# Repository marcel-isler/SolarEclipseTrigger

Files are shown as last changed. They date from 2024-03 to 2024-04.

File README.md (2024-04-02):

Application that remote controls a Nikon D850 during a Solar Eclipse.  The software features the ability to configure different phases in relation to C1 - C4 that can take different sets of photos, including in-camera brackets.  It uses a CH340 USB Relay as a remote shutter trigger.  Instructions on how to create the shutter trigger are in the attached document.

Pre-Requisite:
Install the latest USB Relay Driver:
https://github.com/marcel-isler/SolarEclipseTrigger/blob/main/USB%20Relay/Driver/CH341SER%20v3.8.zip
Install the latest C++ Redistributable:
https://learn.microsoft.com/en-us/cpp/windows/latest-supported-vc-redist?view=msvc-170

Get the executable from the Release Link:
https://github.com/marcel-isler/SolarEclipseTrigger/releases/tag/v0.9.4

These are the steps I'm taking during a run:
1. Format the memory cards in the Camera
2. Set the Camera to LiveView and move the zoom rectangle near the center (the Nikon SDK doesn't have a method to change the location of that rectangle)
3. Clear out the directory where the computer will write the images
4. Connect Camera and USB Relay to Computer (I'm using a USB Hub on the tracker that is connected to the Computer of USB 3.2)
5. Connect the USB Relay to the Remote Shutter Cable on the D850
6. Power on the Camera, verify that you can see the camera from the Computer's File Explorer
7. Start SolarEclipseTimer application
8. Click on the 'Event Info' tab and make sure your event times are correct for your location.  Use a phone app like Solar Eclipse Timer to find the correct contact times for your exact location.  If you had to make any changes, close SolarEclipseTrigger and go back to Point 7.
9. Click on the 'Full Log', then 'Session', then 'Full Log' and 'Session' tab once more (there is a bug with the logging showing up I still have to figure out)
10. Click on 'Set Camera Date Time' in the upper left corner of the application
11. Click on 'Set Focus' tab
12. Click 'Start Focus Procedure' and frame the sun and set the focus.
13. Click 'End Focus Procedure'
14. If this is the REAL run, that's all that should be necessary and the application will countdown to the different phases.
15. If you're running a simulation, uncheck the 'Use System Time' in the Session tab
16. Enter the date and time you want to simulate and press Start.  To do a full run, start 2 minutes before your C1 time, if you just want to test totality, start 2 minutes before C2.

Make sure you run at LEAST one full run with all the equipment setup exactly how you will do it to make sure batteries hold up, timings are ok etc.  Preferably do a full run with the event date in Event Info changed to the current date and the use the actual even times as if it was April 8th.

Camera Settings:
- Camera set to not review photos after they are taken
- Set Live View Photography to CL1
- Just use the XQD / CFExpress card and set the second card to overflow.  Writing to both cards makes the camera slower and can cause issues with the timing of the sequence.
- Disable WiFi and Bluetooth
- Set Camera to Airplane Mode
- Set Camera to Auto Focus and Lens to A/M (needed for software controlled focus drive to work)
- Set Camera to use Back Button Focusing (don't want to trigger autofocus when we take an exposure)

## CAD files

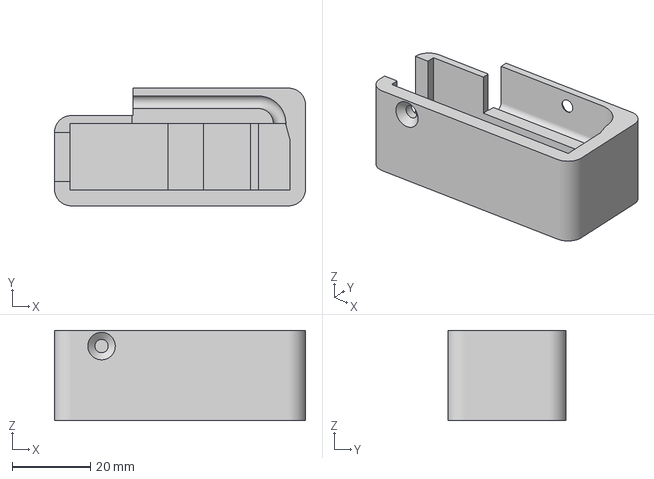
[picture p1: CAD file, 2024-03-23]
USB Relay/Case 3D model/USB Relay Remote Shutter Case Bottom v5.3mf
64.0 x 30.0 x 23.0 mm

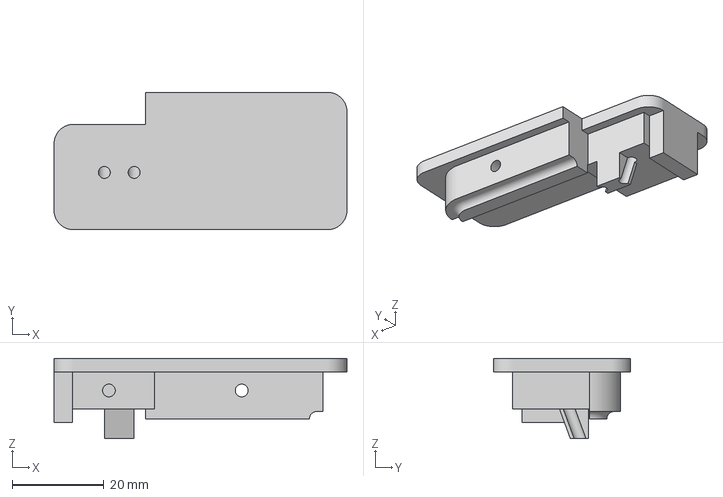
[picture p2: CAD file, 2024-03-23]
USB Relay/Case 3D model/USB Relay Remote Shutter Case Top v5.3mf
64.0 x 30.0 x 17.5 mm

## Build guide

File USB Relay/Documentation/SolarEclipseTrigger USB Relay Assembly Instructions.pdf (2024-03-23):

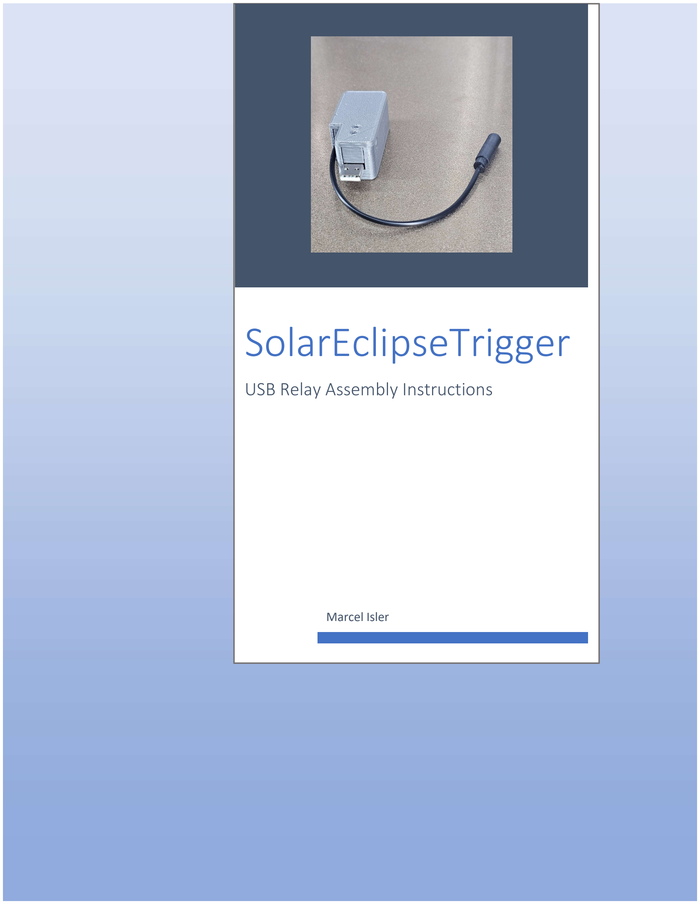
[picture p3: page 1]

# SolarEclipseTrigger

## USB Relay Assembly Instructions

Marcel Isler

## Contents

## 1. Required Materials

- 1 x CH340 USB Relay
- 1 x 2.5mm Female Jack to Bare Wire Open End
- 1 x 2.5mm-N1 10-PIN Remote Control Shutter Release Cable Cord for Nikon D850
- Either: 2 x Small Cable Ties or 1 x 3D printed case

## 2. Amazon Links

This is a list of links to get the materials. There are many vendors that carry those exact same parts, these are just examples. Also, I am not affiliated with any of the vendors below and don’t get any money from possible purchases.

### CH340 USB Relay:

https://www.amazon.com/Taidda-Durable-Lightweight-Intelligent-Control/dp/B07WFVN1FK

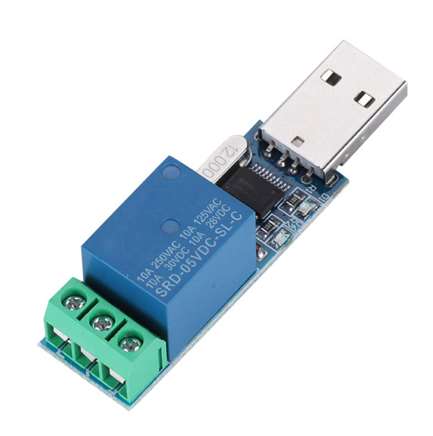
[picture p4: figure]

### 2.5mm Female Jack to Bare Wire Open End:

https://www.amazon.com/dp/B07ZT7JDNP

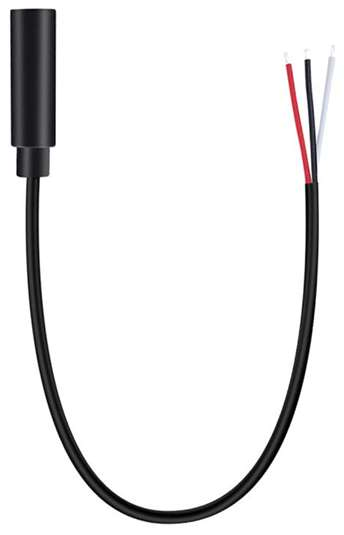
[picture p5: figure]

### 2.5mm-N1 10-PIN Remote Control Shutter Release Cable Cord for Nikon D850

https://www.amazon.com/Foto-Tech-2-5mm-N1-Shutter-Connecting/dp/B017MMBK6G

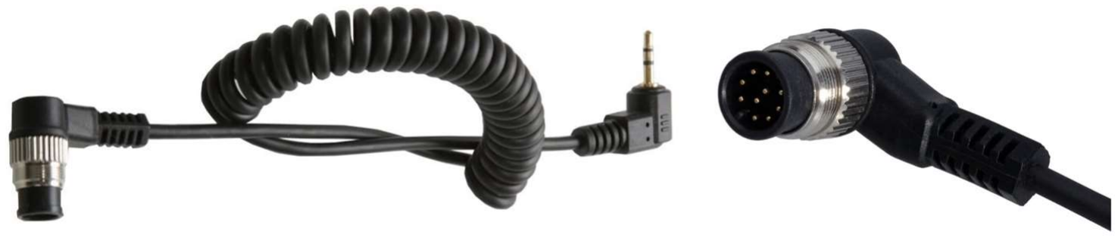
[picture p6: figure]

As an alternative, you can also get a remote shutter control with detachable cable as long as it has a 2.5mm jack plug. That way, should the relay fail for what ever reason, you still have a manual backup to triggering the camera without having to touch it. The more backup solutions we have, the more likely we are to succeed.
https://www.amazon.com/gp/product/B0BFWWC2Y3

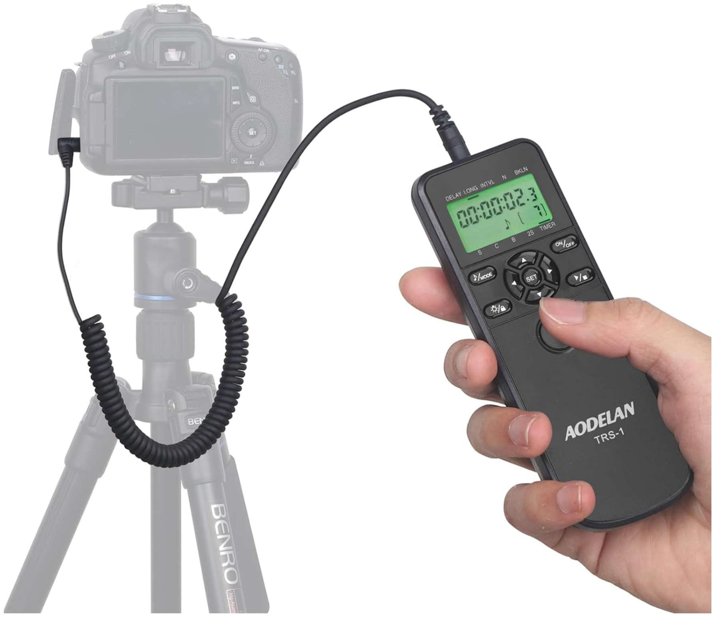
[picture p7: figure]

## 3. Wiring

Wiring up the USB Relay is simple. Strip a bit of insulation from the three wires of the 2.5mm jack cable, twist the red and white wire together, twist the copper end of the black wire by itself. Fold the two copper ends each in half to give it a bit more material inside the connector. Insert the black wire into the center of the Relay connector and the red and white wire pair into the left connector (as seen in the picture below).

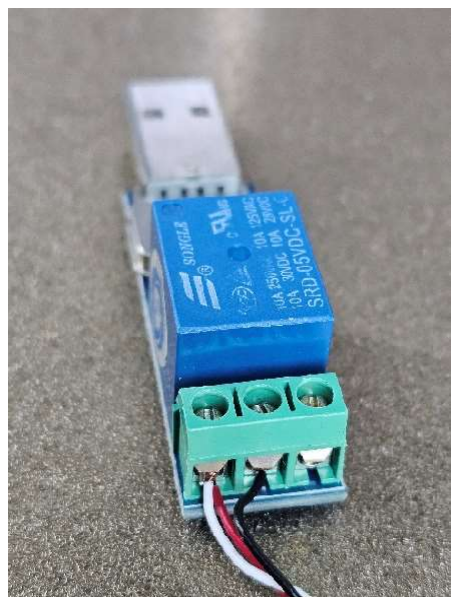
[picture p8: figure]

## 4. Assembly without the 3D case

If you don’t have access to a 3D printer, you can just use two small cable ties to keep the jack cable in place as seen below.

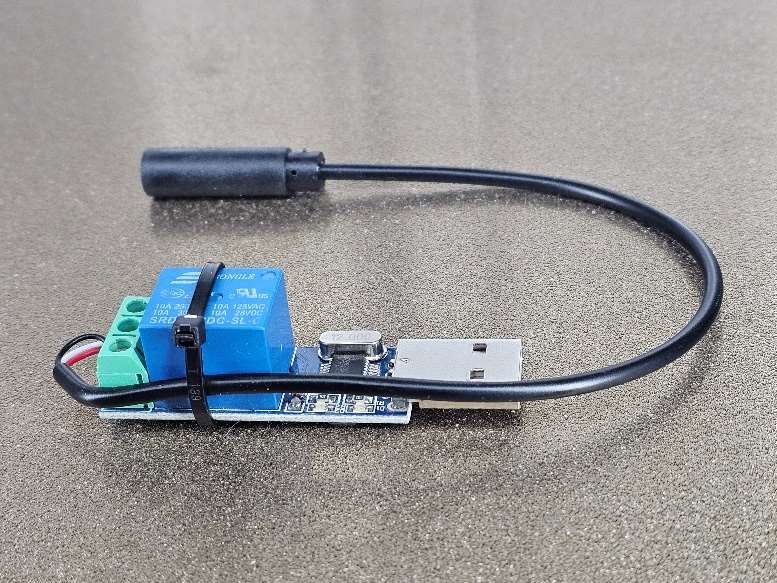
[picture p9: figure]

## 5. Assembly with the 3D case

The model for the case can be downloaded from the github site below: https://github.com/marcel-isler/SolarEclipseTrigger
Print the two halves in PETG with 0.2mm layer height on a well calibrated 3D printer.

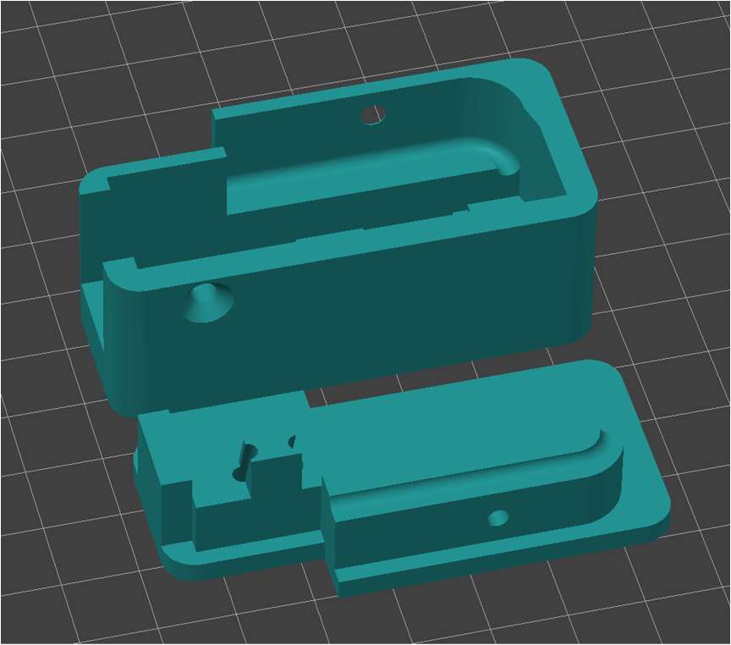
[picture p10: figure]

Once the parts are printed, you can insert the Relay into the bottom half and route the jack cable through the channel on the left side to the outside. Make sure the cable is nicely in the channel, so it won’t get pinched by the top half.
Make sure the Relay is well seated in the bottom half and then insert the top half. Use two M3 x 8mm countersunk screws to screw the top half in place.

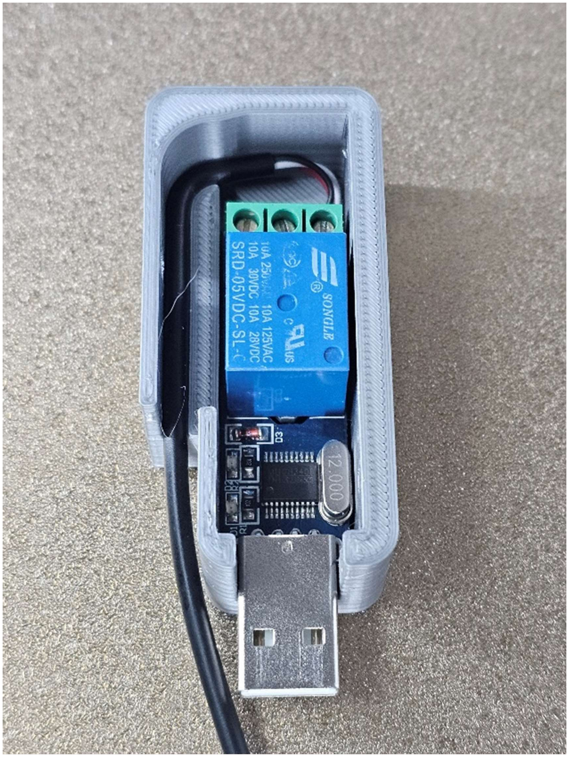
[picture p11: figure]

Optionally, you can add two plastic light guide fibers into the two holes at the top of the case. I’m using the following light guide:
https://www.amazon.com/gp/product/B09J15N8W5

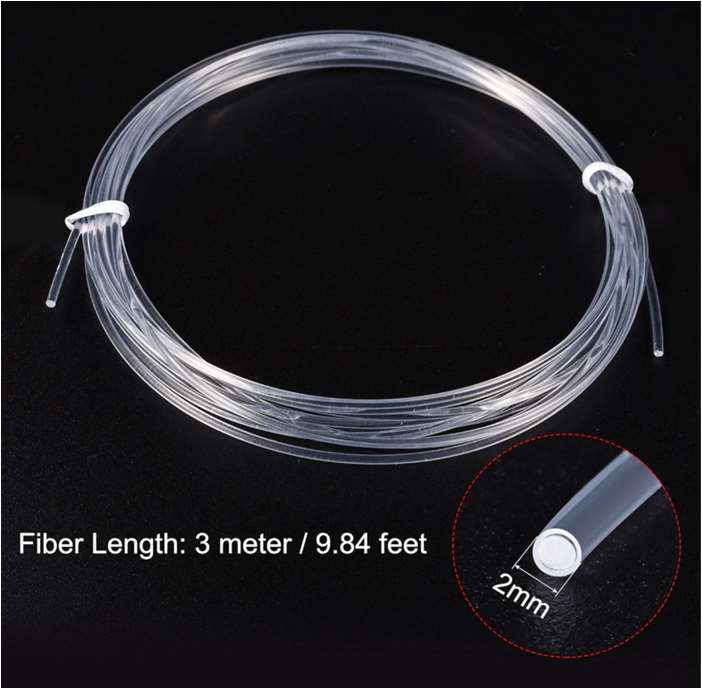
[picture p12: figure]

When you insert the light guide, it’s easiest to push the light guide into the hole from the inside until it comes out at the top by a few mm. Then cut it flush at the top with a sharp knife. Then repeat for the second hole. This makes it easier to see when the LEDs light up inside the case.

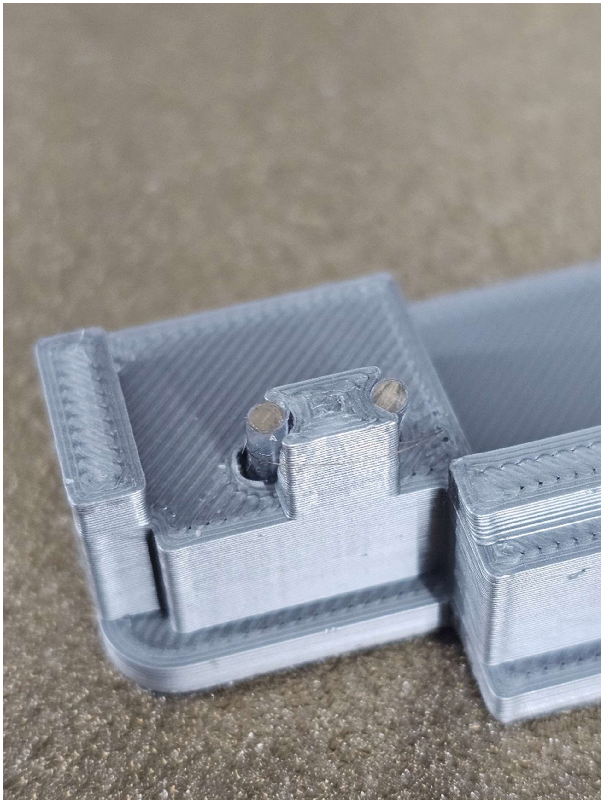
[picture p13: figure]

## 6. Final Product

This is what it should look like after complete assembly:

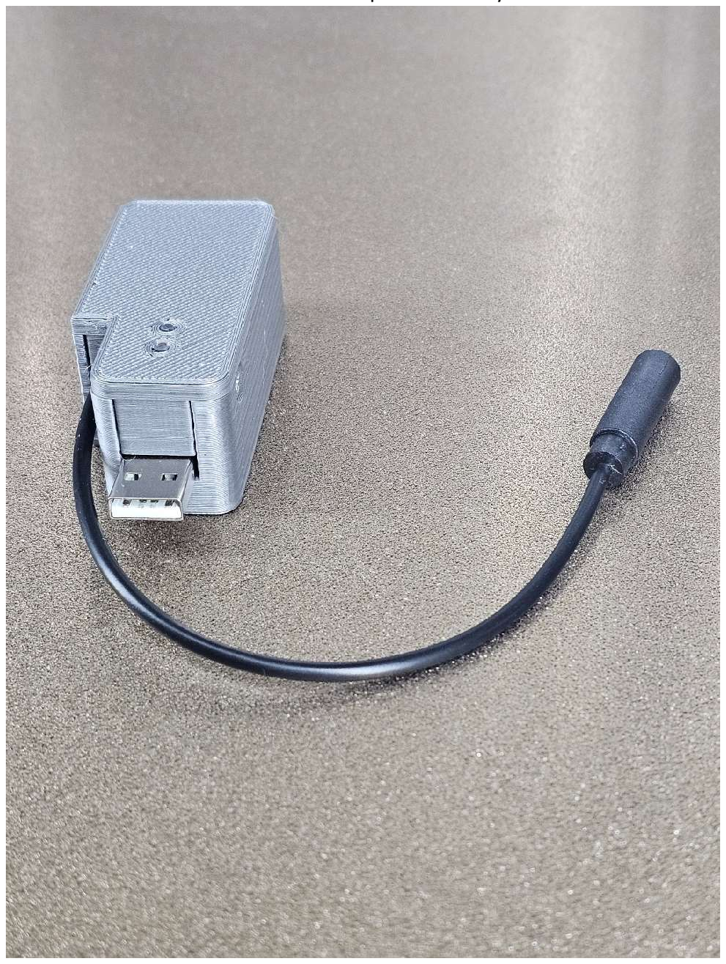
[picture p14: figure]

## 7. Configuration

To make sure the Relay works, insert it into a USB plug on your computer. The light closer to the USB connector should light up.

### Determine the COM port being used

Then go into the Windows Device Manager (type Device Manager in the Search box in your Task Bar and it should show up), then look for Ports (COM & LPT) and expand that section. Note down the COM port the CH340 is using, you will need that to update the SolarEclipseTrigger config file.

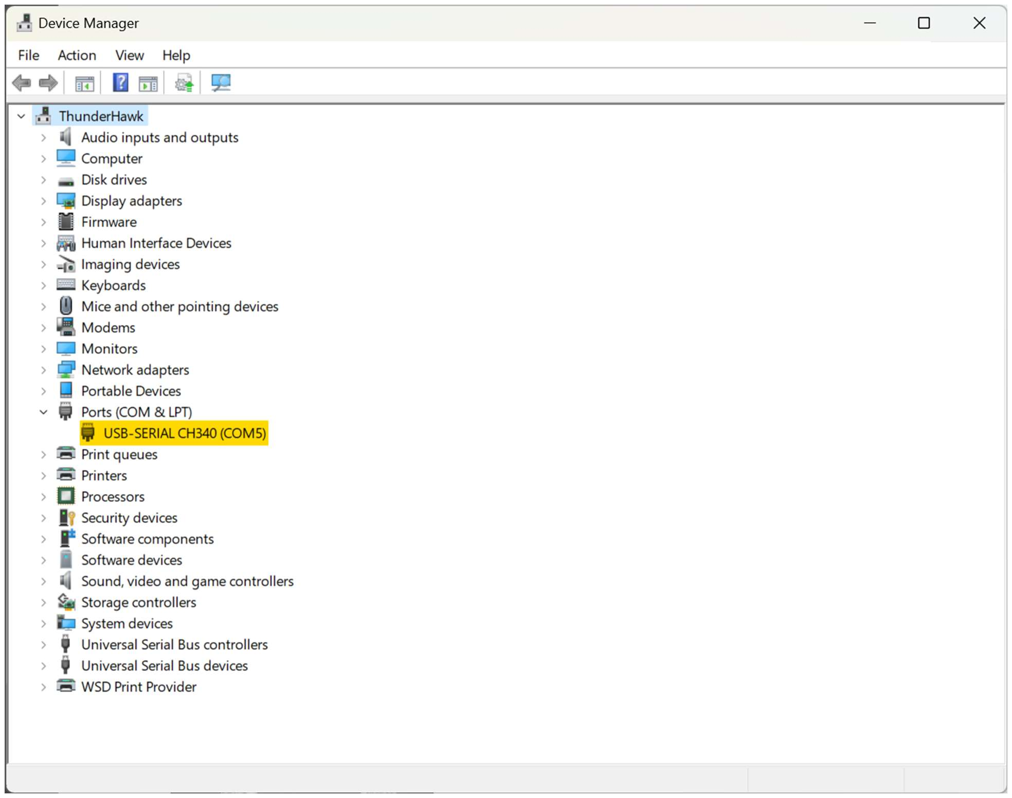
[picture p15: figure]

### Modify the SolarEclipseTrigger.exe.config file

Open the file “SolarEclipseTrigger.exe.config” in the folder where you have the SolarEclipseTrigger application with NotePad or any other Text Editor.
Look for the <appSettings> section

<appSettings>
<add key="SerialPort" value="COM5" />
<add key="EventInfoFile" value="EventInfo.json" />
<add key="SessionPhasesFile" value="SessionPhases.json" />
<add key="CameraName" value="D850" />
<add key="CameraFileLocation" value="\Removable storage 10001\DCIM\" /> <add key="LocalFileLocation" value="D:\SolarEclipseFiles\" /> </appSettings>
and change the value of the “SerialPort” entry to the COM value you saw in the Device Manager.
While at it, also verify that the CameraFileLocation matches the DCIM folder on the memory card you’re using. To do that, connect the D850 by USB to your computer, open it with File Explorer and verify the path.
Then set the path of the “LocalFileLocation” to where you want SolarEclipseTrigger to store any files it downloads from the camera.

## 8. Testing

With the USB Relay plugged into a USB port on your computer, plug the 2.5mm jack of the remote shutter cable into the 2.5mm socket of the relay, then connect the 10 pin connector to the remote shutter port of the D850.
Connect the D850 over USB to your computer and turn the camera on.
It’s best to always format the SD cards on the D850 before a recording session with SolarEclipseTrigger. NOTE: Make sure you have the images on the card backed up / imported into your computer before formatting the cards!
Start SolarEclipseTrigger and wait for the main window to open. Go to the Phases tab, select the Exposure Test phase in the list on the left and click on “Test Fire Phase”. That should fire 3 brackets of 9 exposures each. Disconnect the camera from the USB port and review the images in the camera.

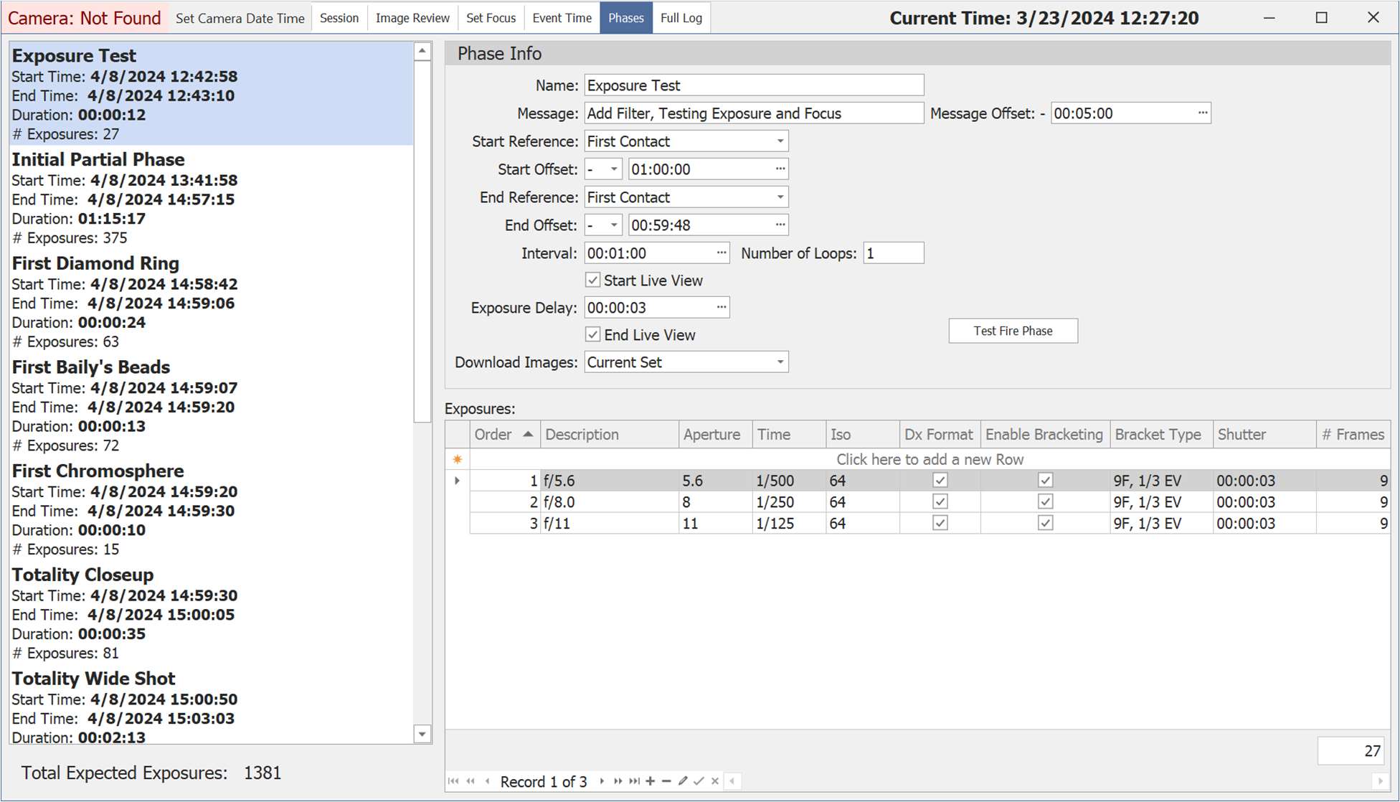
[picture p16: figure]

If you have 27 photos on your SD card, you have successfully passed the USB Relay test.

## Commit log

2024-03-23 Added USB Relay 3D model and Driver
    [USB Relay Remote Shutter Case Bottom v5.3mf, USB Relay Remote Shutter Case Top v5.3mf]
2024-03-23 Added assembly instructions for the USB Relay
2024-03-23 Added additional information to the assembly instructions
2024-04-01 Uploaded new version of the CH340 driver for the USB relay
